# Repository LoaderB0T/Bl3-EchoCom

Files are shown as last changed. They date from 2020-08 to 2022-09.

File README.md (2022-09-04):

# Borderlands 3 - Echo Device

This repo contains all the needed files to create your own 3D printed Echo Com from Borderlands 3.
I put lots of images in the repo so the size got quite big, sorry for that 🤷‍♂️.

If you need additional information or have any questions please just open an issue and I will try to answer them 😀.
And please, if you decide to give it a shot and you use my model, please please send me pictures of the result! :) Just open an issue here to show off your amazing work.

## Printing

- I printed all opaque parts with PLA filament with 0.15mm layer height.
- For the electronics version, the inner projector part was printed with "transparent" PETG filament to let the light of the LEDs pass through.
- I Recommend printing more or less everything with full support to make sure all the complex parts get printed properly.
- Removing the supports is quite easy with this model.

## Components for the electronics version

- [4" TFT Display](https://www.waveshare.com/4inch-tft-touch-shield.htm)
  - I really recommend buying exactly this one as the 3D model is designed for exactly this product.
  - It was the only display I found that had the correct size for the EchoCom.
  - You have to remove the pin headers from the backside for it to fit into the model. The required wires then can be re-soldered with a thinner footprint.
- Custom PCB
  - You can find the KiCad project and a finished plot of the PCB in the `pcb` folder.
  - Use a service like [JLCPCB](jlcpcb.com) to have it manufactured or you can of course do it yourself :)
- Electronic Components:
  - 1x Atmega328P-PU
  - 8x Push Button
  - 2x 22pF ceramic capacitors
  - 1x 16MHz Crystal
  - 3x 100nF foil capacitor
  - 1x 10K Ohm resistor
  - 2x Digital RGB LEDs (eg WS2812B) (one or maybe more than two might also work for you)
  - 2x Screw Terminals (optional, you can also solder the power wires)
  - Pin Header (optional, you can also solder the wires, but I recommend the headers!)
    - 2x 3-pin
    - 2x 5-pin
    - 1x 6-pin
- Some sort of power source (I have not yet figured this out)
- Wires (with correct heads depending on your pin headers)

## Code

The code is very, very unfinished!
I recommend [Visual Studio Code](https://code.visualstudio.com/) to edit the code. The code is a [PlatformIO](https://platformio.org/) project, so I recommend the [PlatformIO extension](https://marketplace.visualstudio.com/items?itemName=platformio.platformio-ide) for VSCode.

## Images

| | | |
| :---: | :---: | :---: |
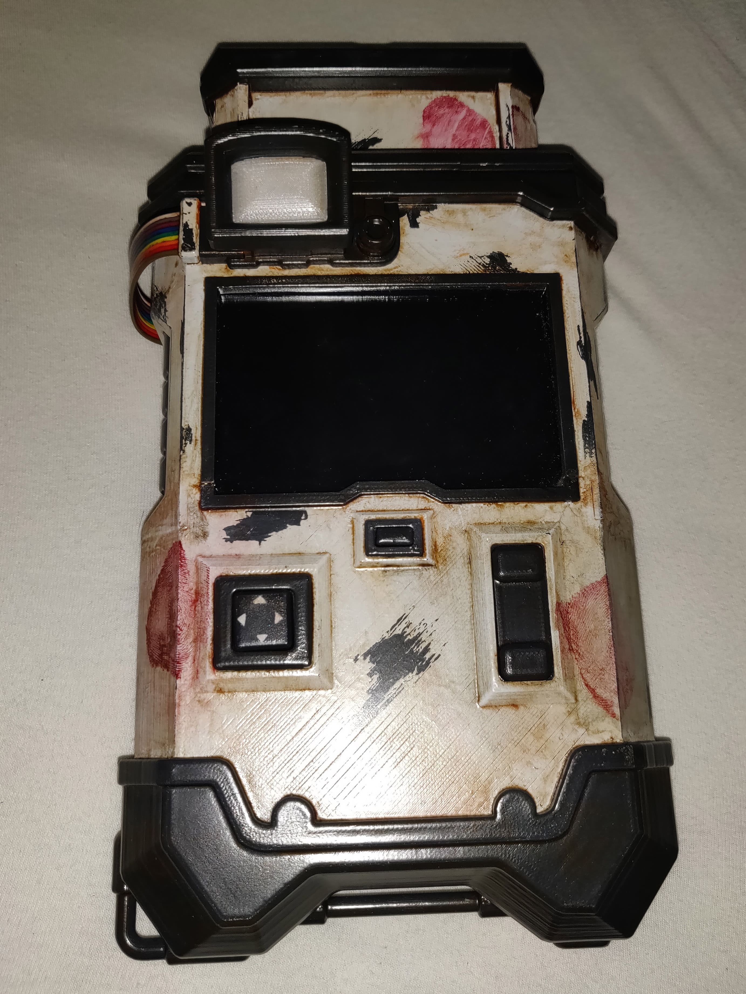
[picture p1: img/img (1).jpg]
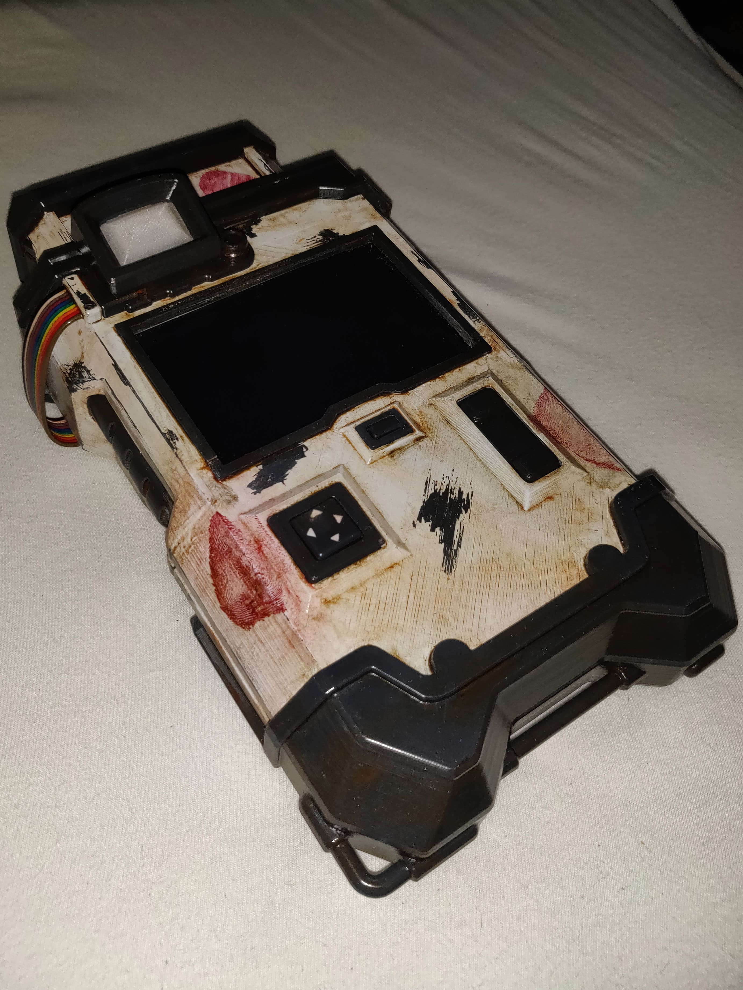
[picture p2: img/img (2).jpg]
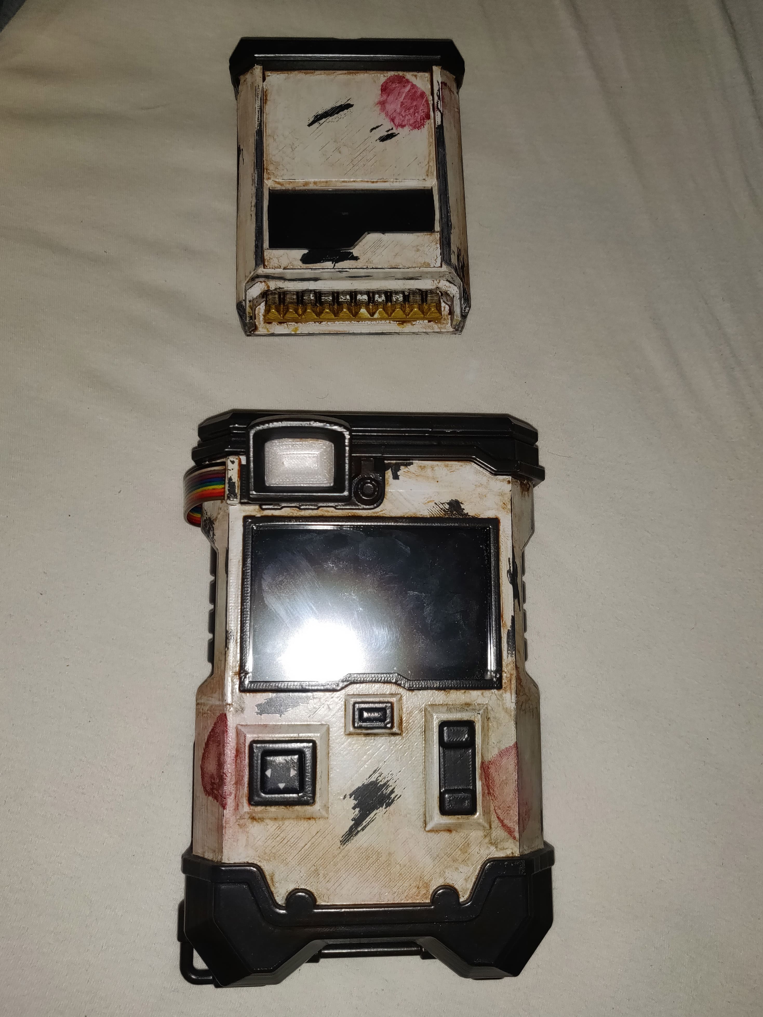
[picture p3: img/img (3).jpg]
|  |   |   |
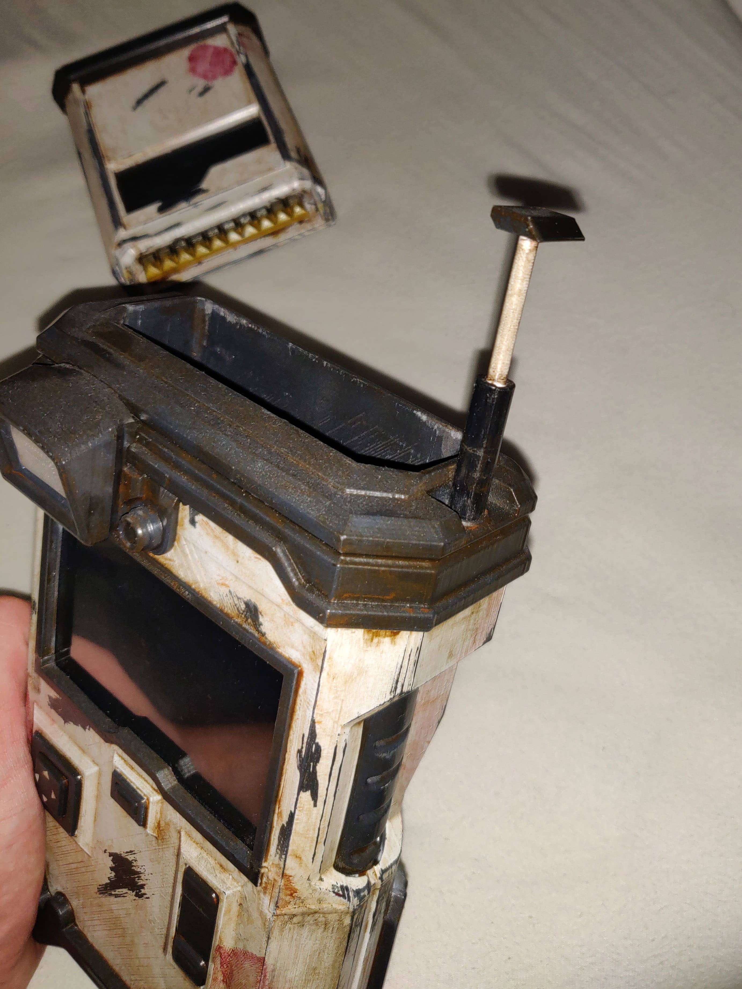
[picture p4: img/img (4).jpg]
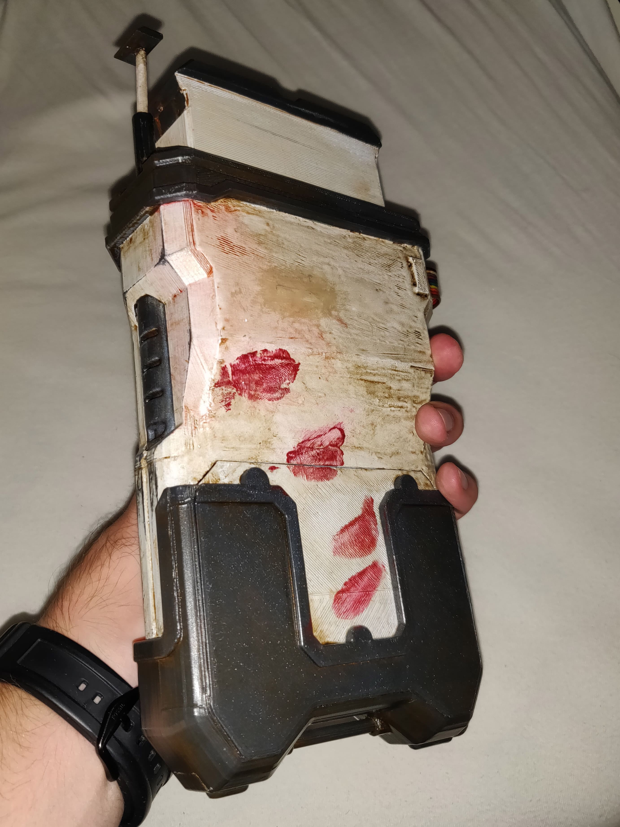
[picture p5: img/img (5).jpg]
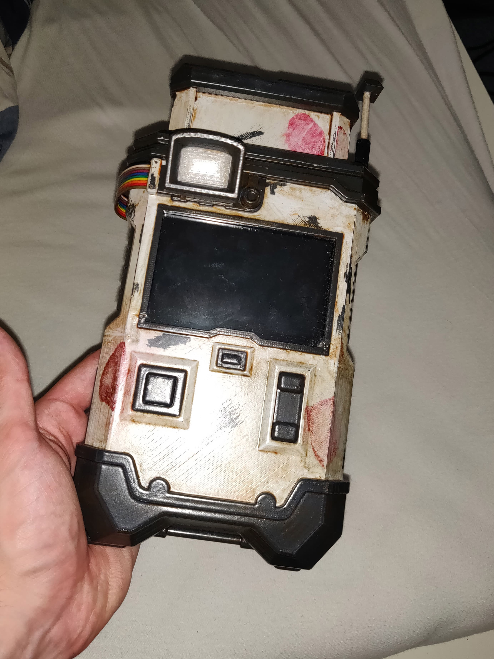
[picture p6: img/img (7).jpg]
|  |   |   |
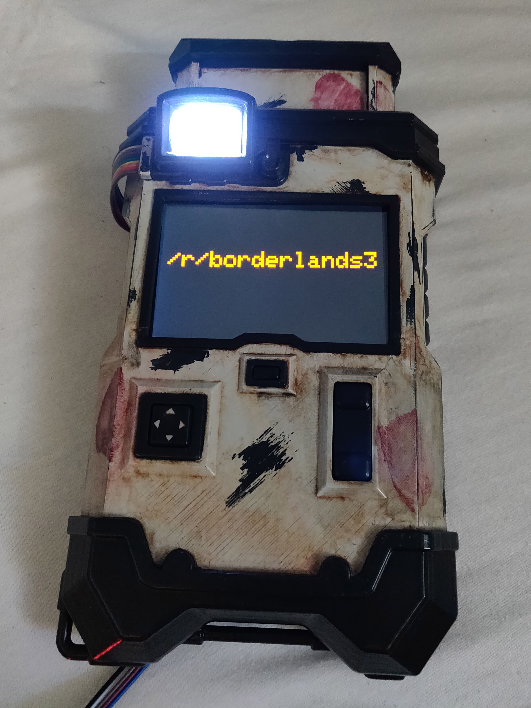
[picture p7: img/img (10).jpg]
|  |  |  |

## Progress images

| | | |
| :---: | :---: | :---: |
|  |  |  |
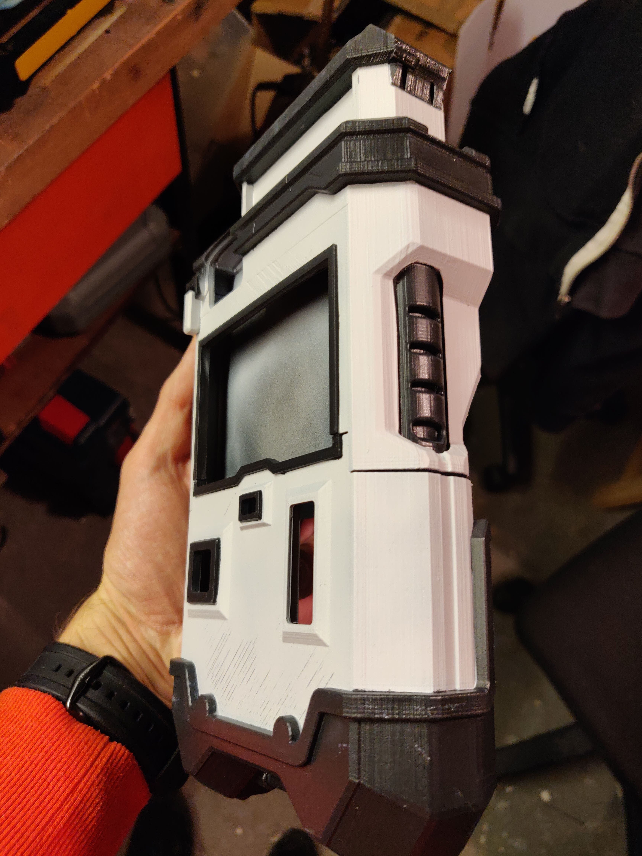
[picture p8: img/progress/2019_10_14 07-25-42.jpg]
|  |  |  |
|  |  |  |
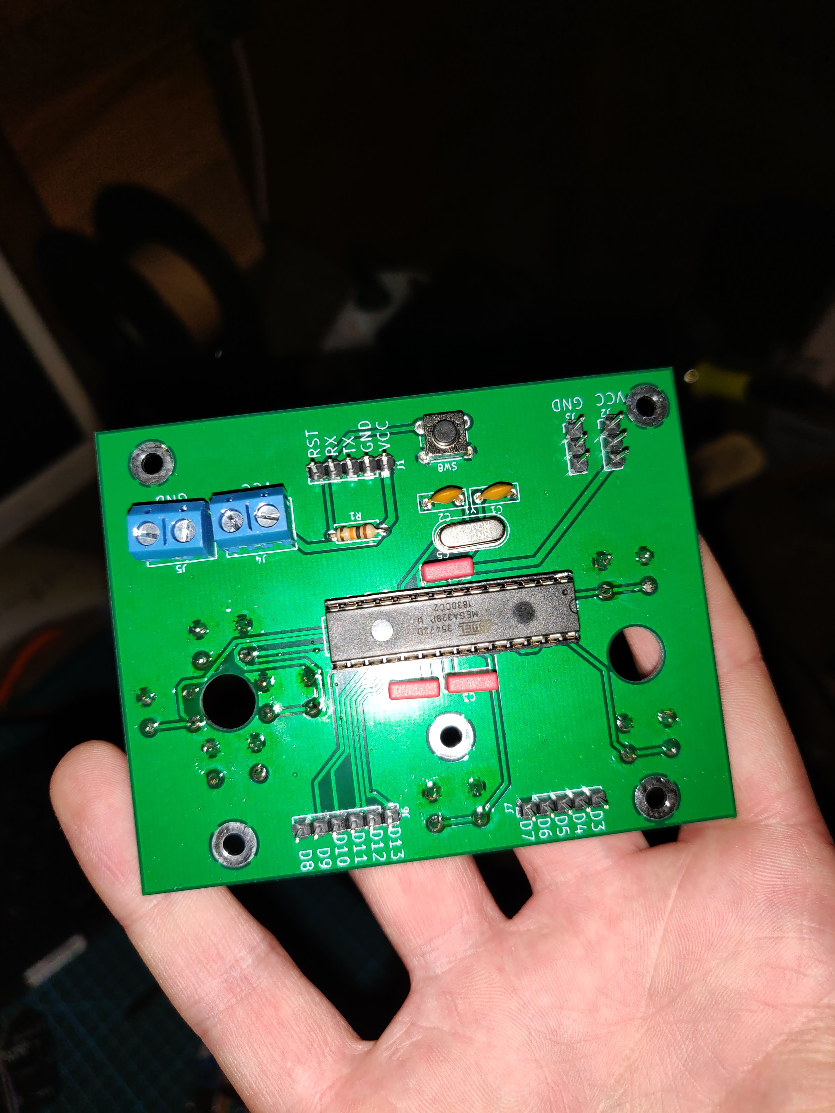
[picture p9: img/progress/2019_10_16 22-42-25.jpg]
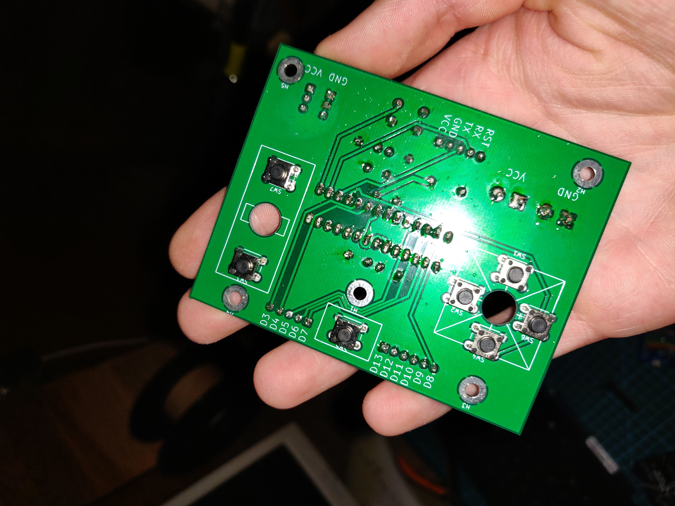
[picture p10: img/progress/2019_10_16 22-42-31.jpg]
|  |  |  |
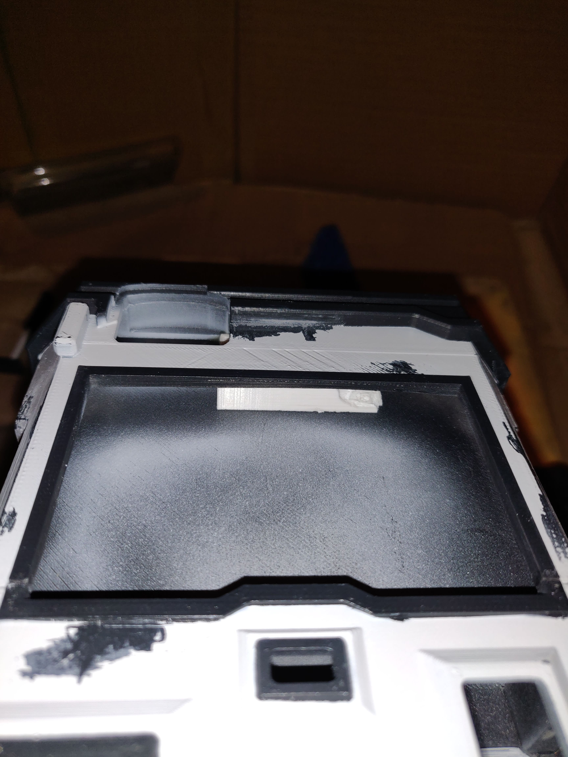
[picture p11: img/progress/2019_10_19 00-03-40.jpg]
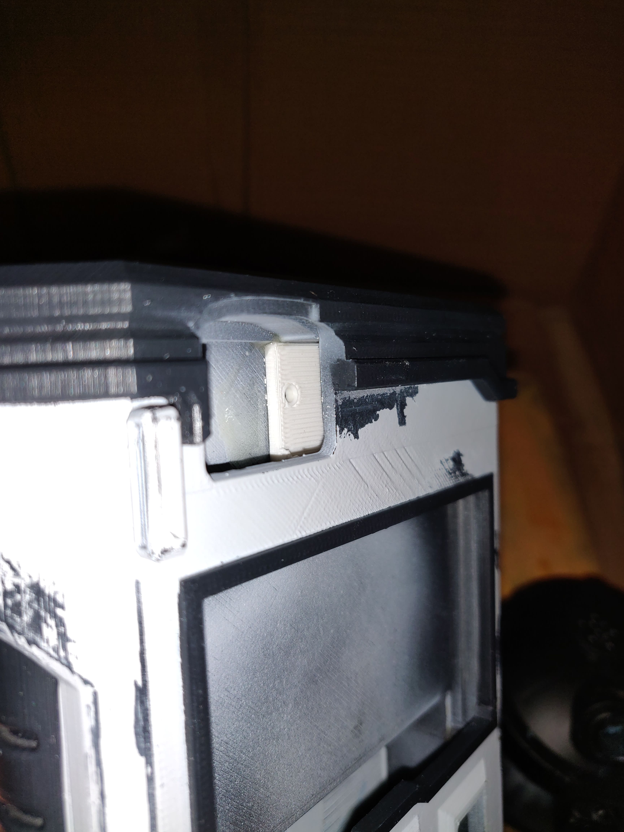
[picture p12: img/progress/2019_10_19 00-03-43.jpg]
|  |  |  |
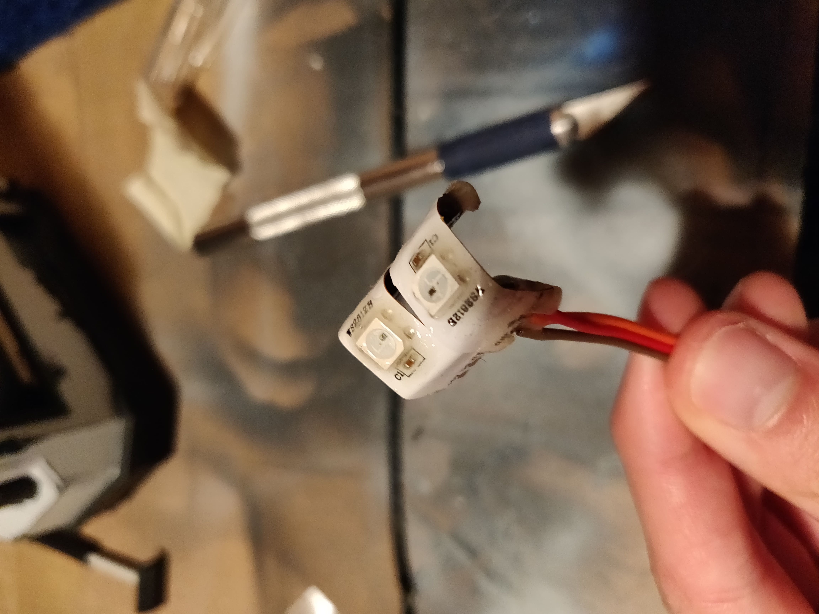
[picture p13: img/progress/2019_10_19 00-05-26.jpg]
|  |  |  |
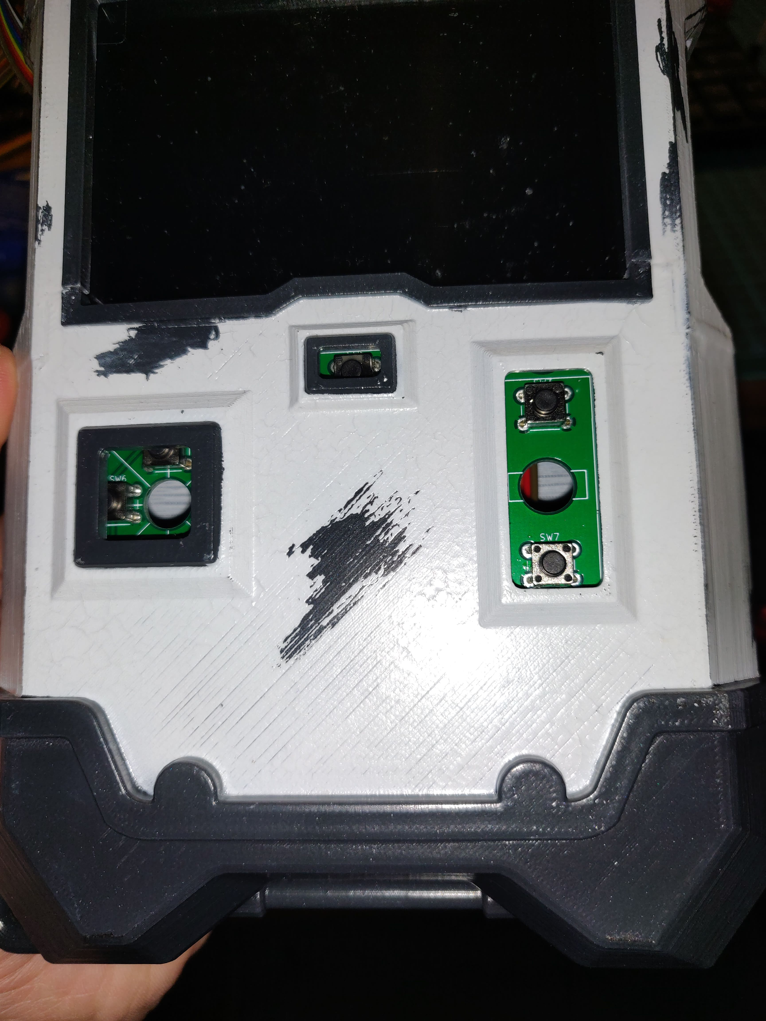
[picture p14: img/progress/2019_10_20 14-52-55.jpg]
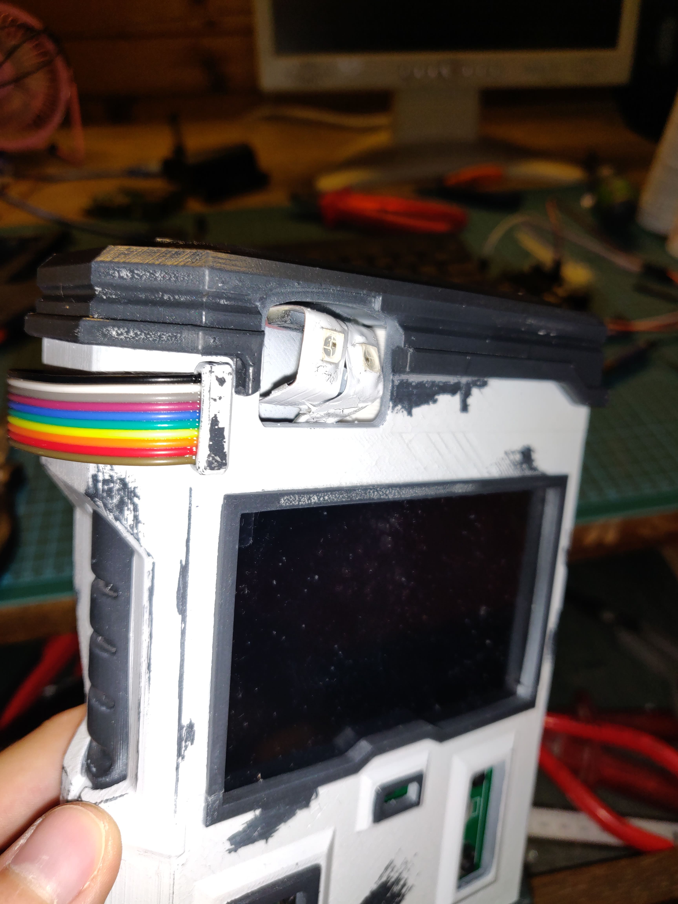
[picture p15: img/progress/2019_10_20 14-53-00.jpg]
|  |  |  |
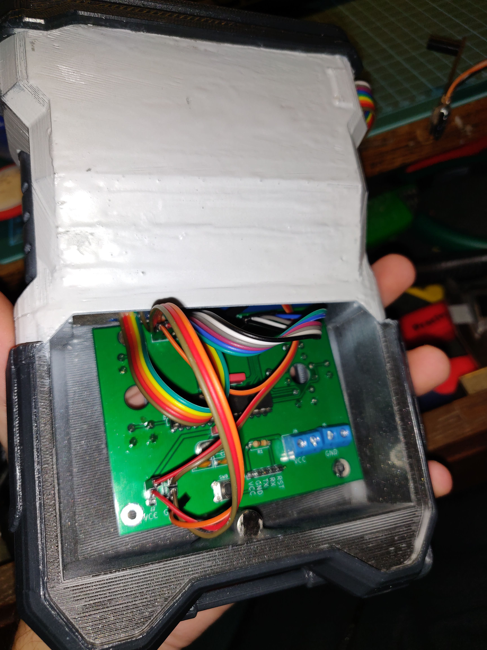
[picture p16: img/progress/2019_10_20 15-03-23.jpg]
|  |  |  |
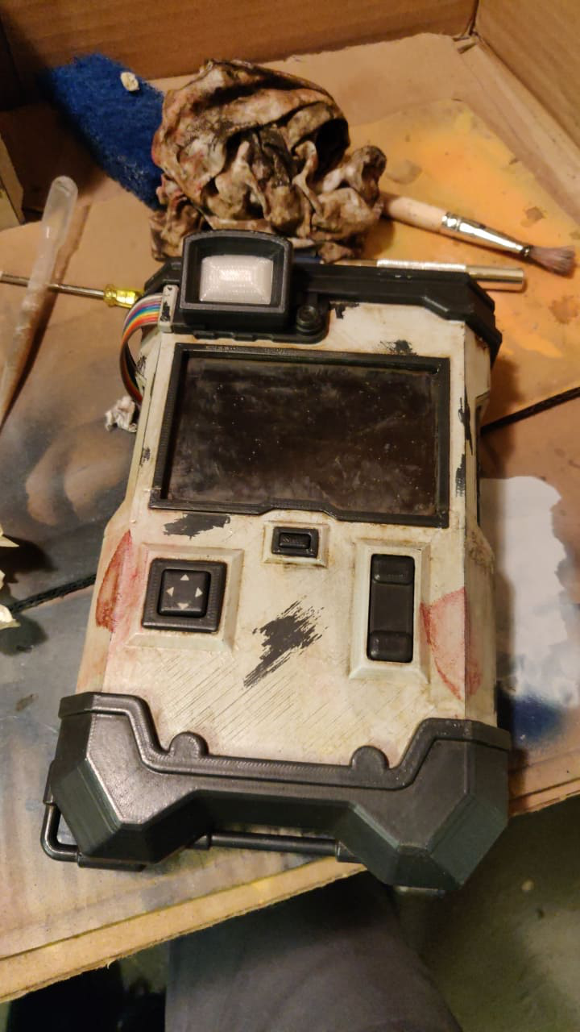
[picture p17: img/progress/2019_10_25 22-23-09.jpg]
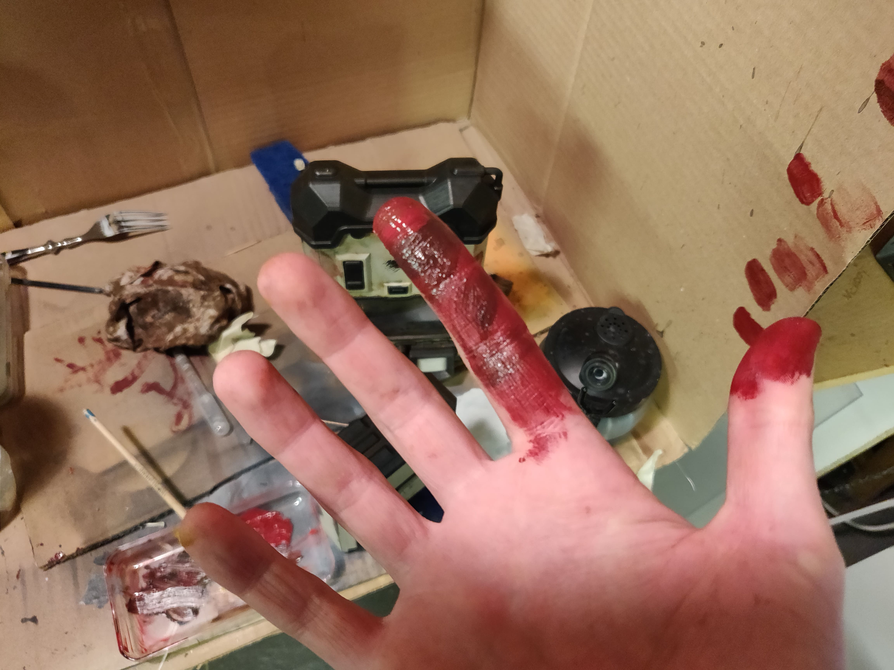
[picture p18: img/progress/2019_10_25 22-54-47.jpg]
|  |  |  |
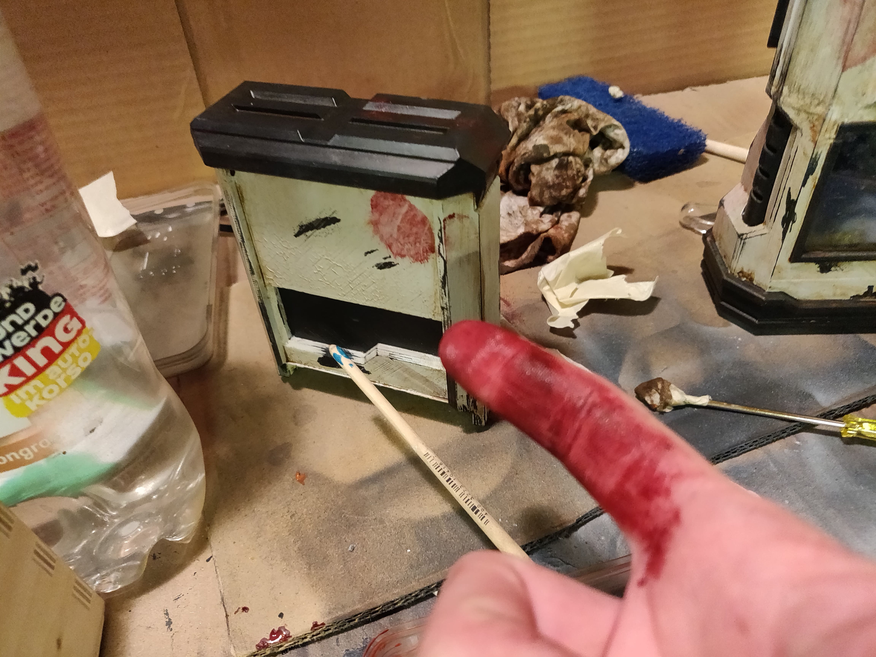
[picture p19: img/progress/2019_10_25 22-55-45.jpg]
|  |  |

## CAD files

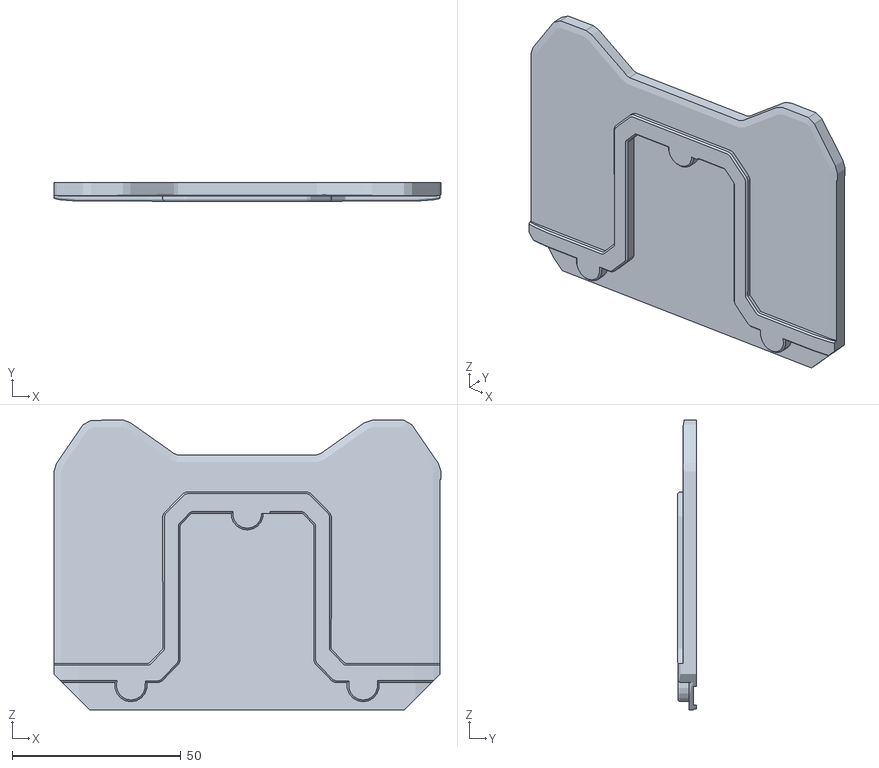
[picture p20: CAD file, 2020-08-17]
stl/electronics version/echoCom BackPlane.stl
114.6 x 5.52 x 85.8

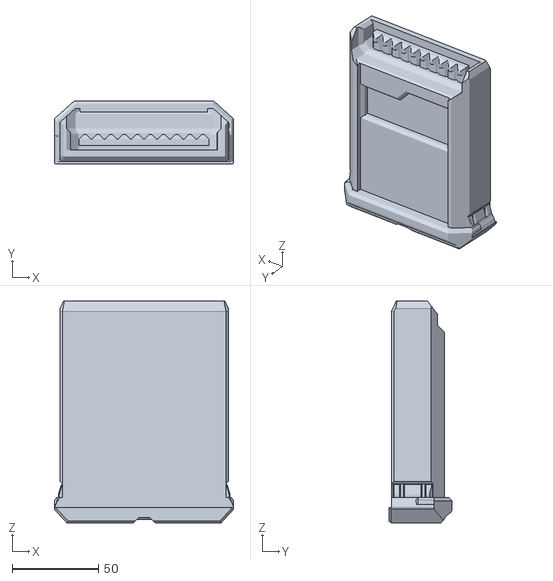
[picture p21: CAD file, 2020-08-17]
stl/solid version/echoCom Solid disk.stl
103.9 x 36.5 x 128.6

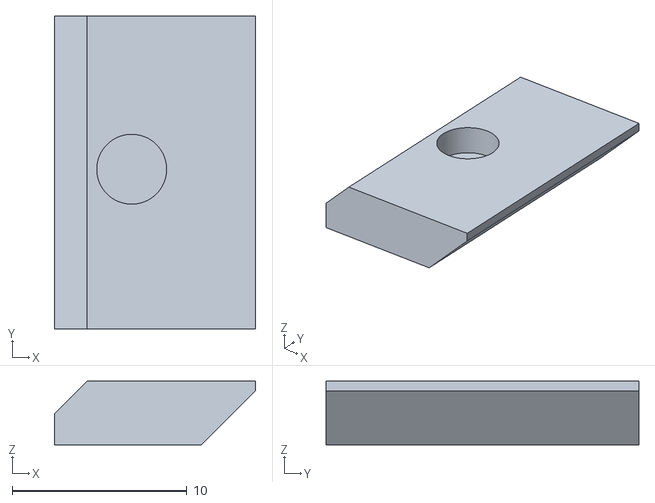
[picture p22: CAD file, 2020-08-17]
stl/electronics version/echoCom AntennaThingy.stl
11.5 x 17.9 x 3.66

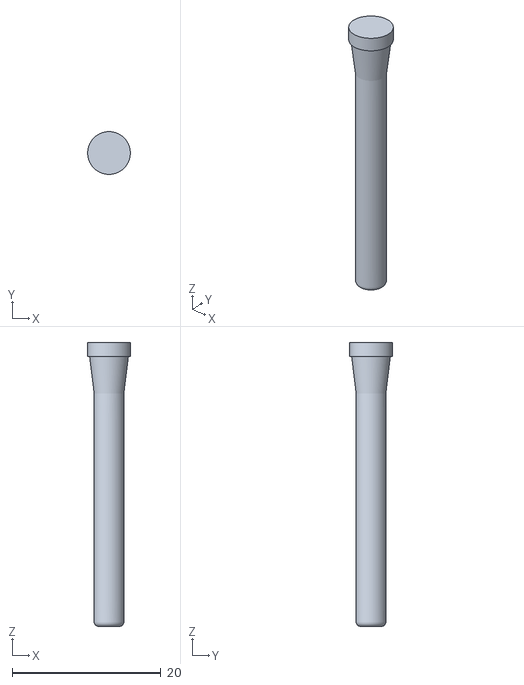
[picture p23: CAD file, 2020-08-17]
stl/solid version/echoCom Solid AntennaUpper.stl
5.74 x 5.74 x 38.1

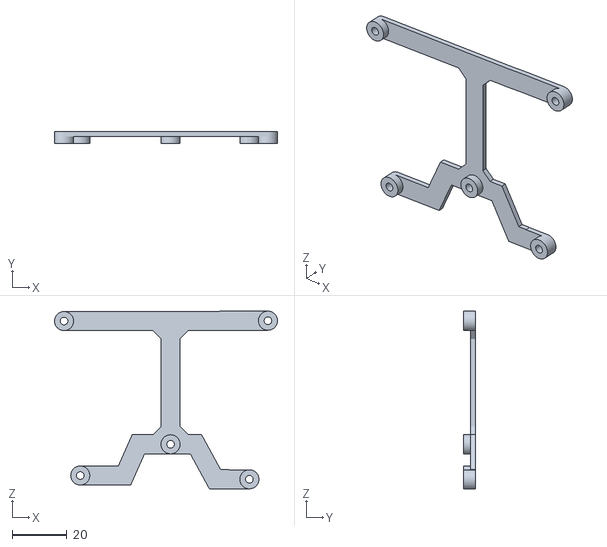
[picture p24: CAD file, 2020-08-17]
stl/electronics version/echoCom PCB Holder.stl
81.7 x 4.50 x 65.1

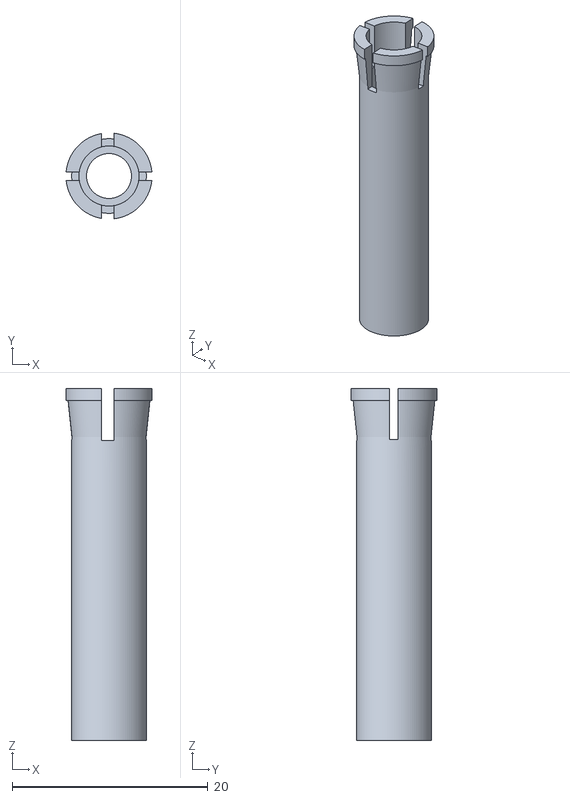
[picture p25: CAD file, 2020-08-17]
stl/solid version/echoCom Solid AntennaLower.stl
8.77 x 8.75 x 36.0

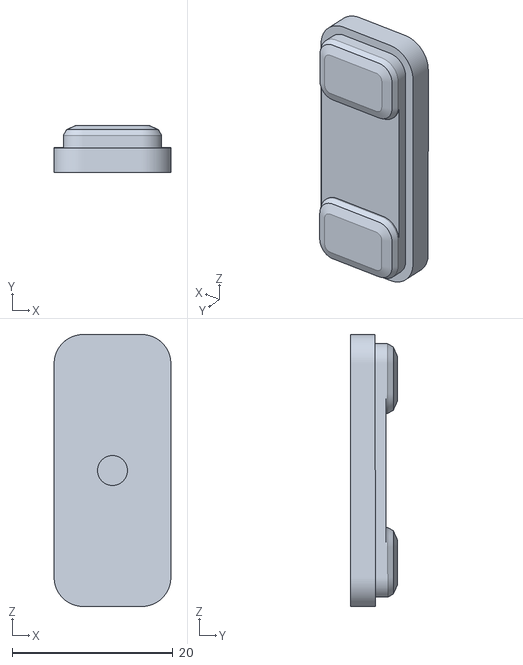
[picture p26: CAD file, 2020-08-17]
stl/electronics version/echoCom ButtonDouble.stl
14.5 x 5.90 x 33.8

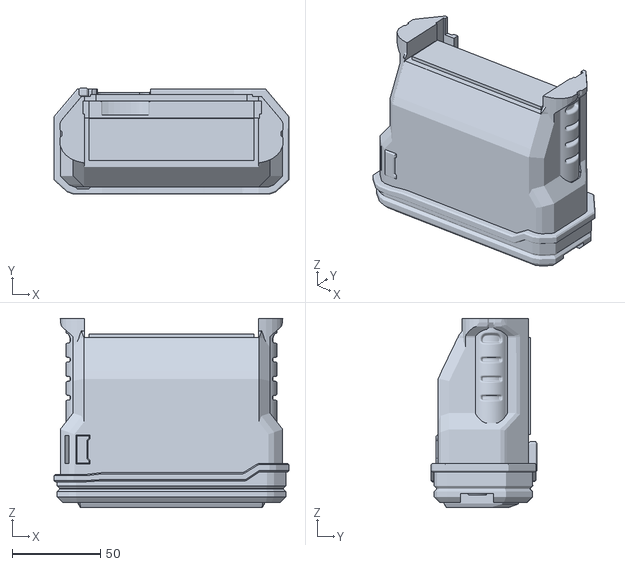
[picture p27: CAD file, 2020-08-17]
stl/electronics version/echoCom Top.stl
133.2 x 60.3 x 107.2

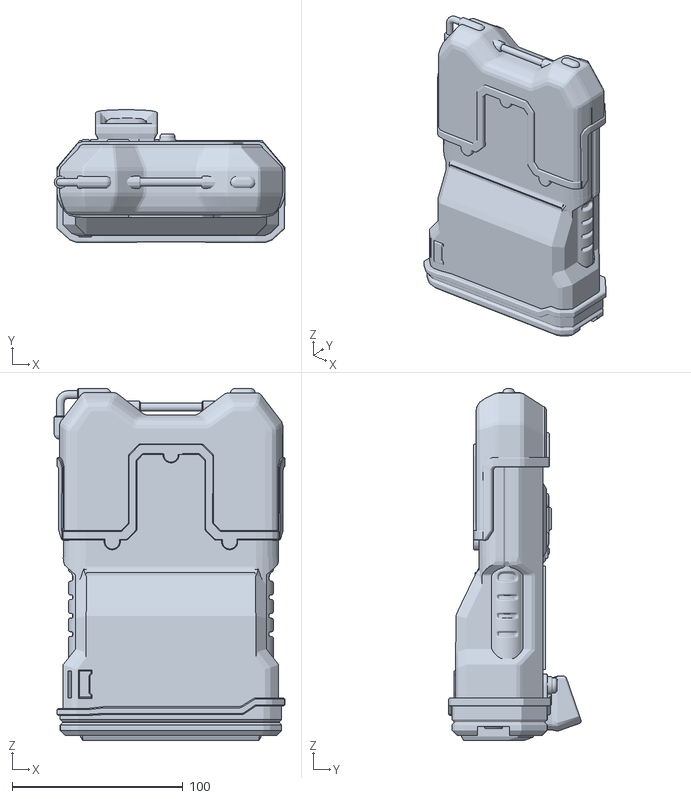
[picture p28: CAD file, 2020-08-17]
stl/solid version/echoCom Solid body.stl
135.0 x 77.6 x 206.0

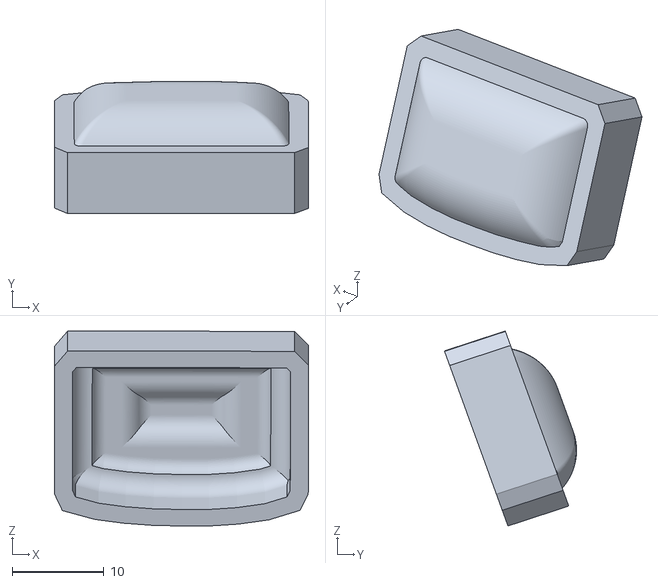
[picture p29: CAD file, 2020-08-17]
stl/electronics version/echoCom ProjectorInner.stl
27.6 x 14.4 x 21.2

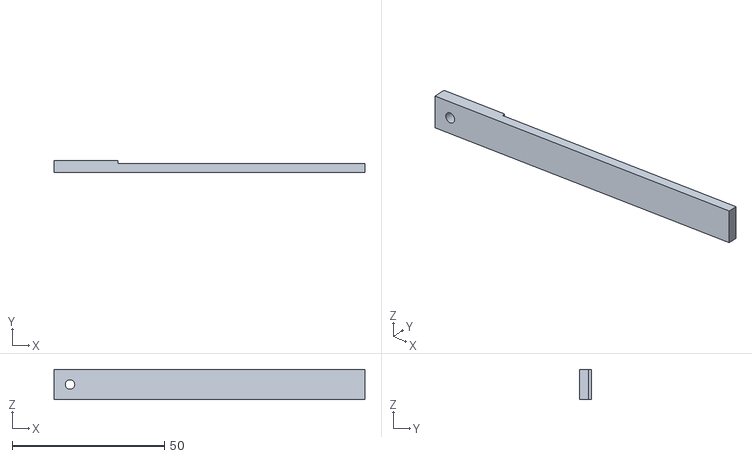
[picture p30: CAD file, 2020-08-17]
stl/electronics version/echoCom pcb holder upperstl.stl
102.0 x 4.00 x 10.0

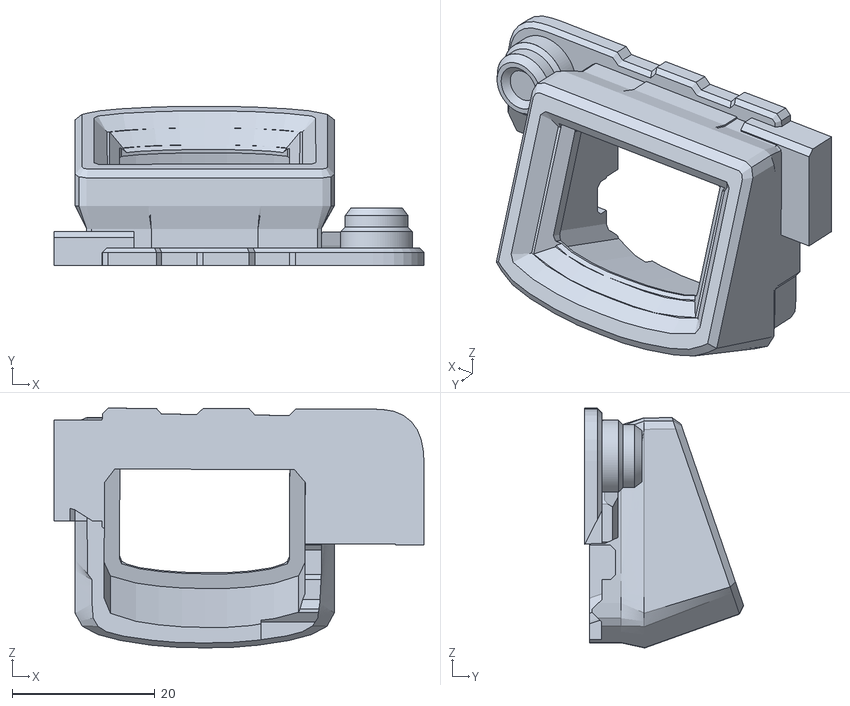
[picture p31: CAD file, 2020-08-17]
stl/electronics version/echoCom Projector.stl
51.9 x 22.3 x 33.6

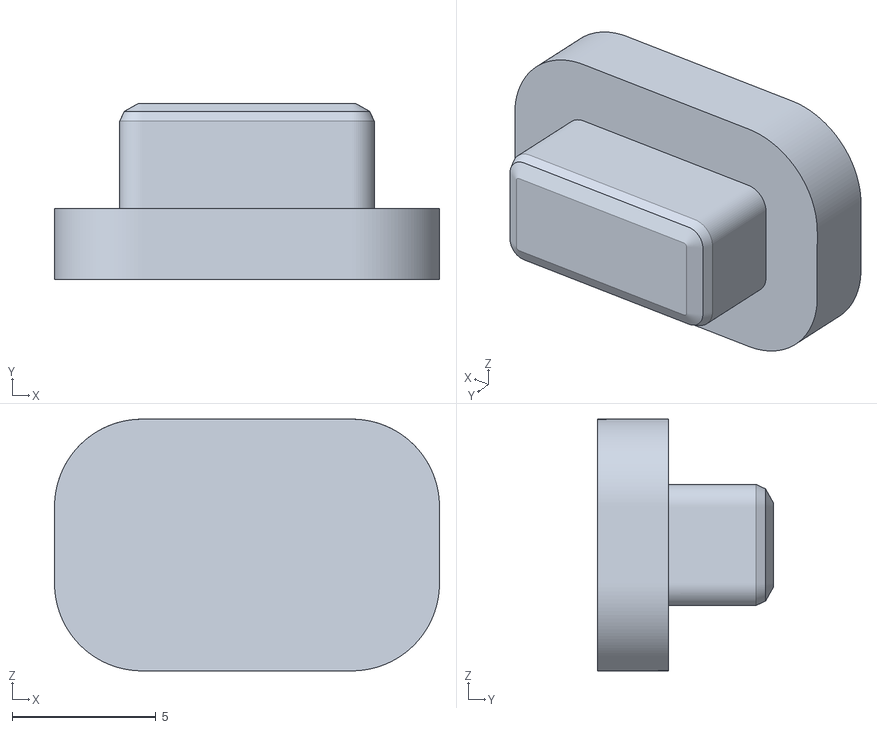
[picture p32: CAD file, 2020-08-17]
stl/electronics version/echoCom ButtonSmall.stl
13.4 x 6.14 x 8.76

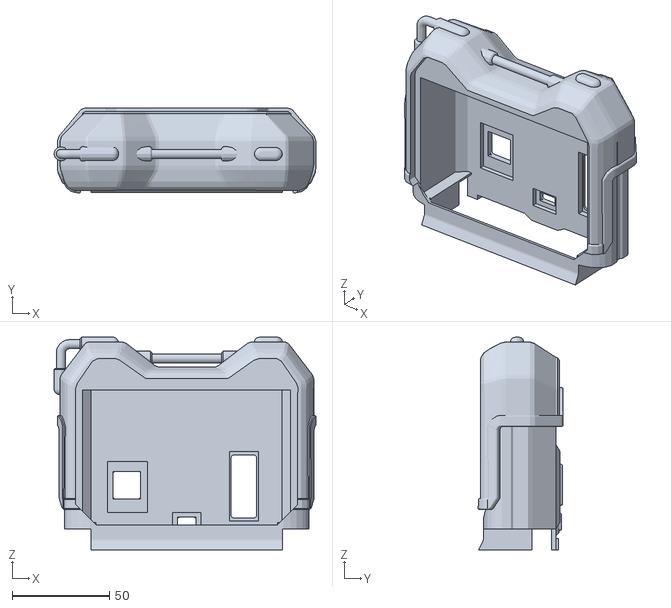
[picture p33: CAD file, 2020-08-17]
stl/electronics version/echoCom Bot.stl
135.0 x 44.0 x 109.6

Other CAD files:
stl/electronics version/echoCom ButtonSquare.stl

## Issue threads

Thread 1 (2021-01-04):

power source suggestion

voxbox31, 2021-01-04:
have you considered using a the echo recording piece (the top removable piece) as a battery bank? maybe a lithium ion circuit or a bank of 18650s?

LoaderB0T, 2021-01-04:
Neat idea, but I think I wouldn't want the echo device to require the 'disk' to work.

Since creating the repo I have not continued working on this project at all (neither software nor hardware)

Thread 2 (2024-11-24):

Could you provide a solid STEP file of the entire device with no internal cutouts please?

tripartist1, 2024-11-24:
Trying to adapt this to a phone case for someone and a step file without the cutaways for electrons would make it much easier. Thanks!

LoaderB0T, 2024-11-24:
Hi there! :)

Did you check the solid version in the STL folder? Sounds like it's exactly what you need :)

Regards,
Janik

tripartist1, 2024-11-26:
Hey, I did check but there doesnt seem to be one single "full model" that isn't already split up unless I missed it. I also use CAD to do my modeling so the STL format makes it somewhat difficult to edit, that's why I requested the step format if possible.

LoaderB0T, 2024-11-28:
I appreciate that the STL might not be as comfortable to work with as a STEP file. Unfortunately, at this moment, I can't provide you with a STEP version.
If you decide to work with the STLs, the solid version has a few STLs, but the main body of the device is [one single solid STL](https://github.com/LoaderB0T/Bl3-EchoCom/blob/master/stl/solid%20version/echoCom%20Solid%20body.stl).

The other STLs in the folder are the disk and three antenna parts. I am sure you can figure out a way to connect the upper part of the antenna, the disk, and the main body into a single object :)

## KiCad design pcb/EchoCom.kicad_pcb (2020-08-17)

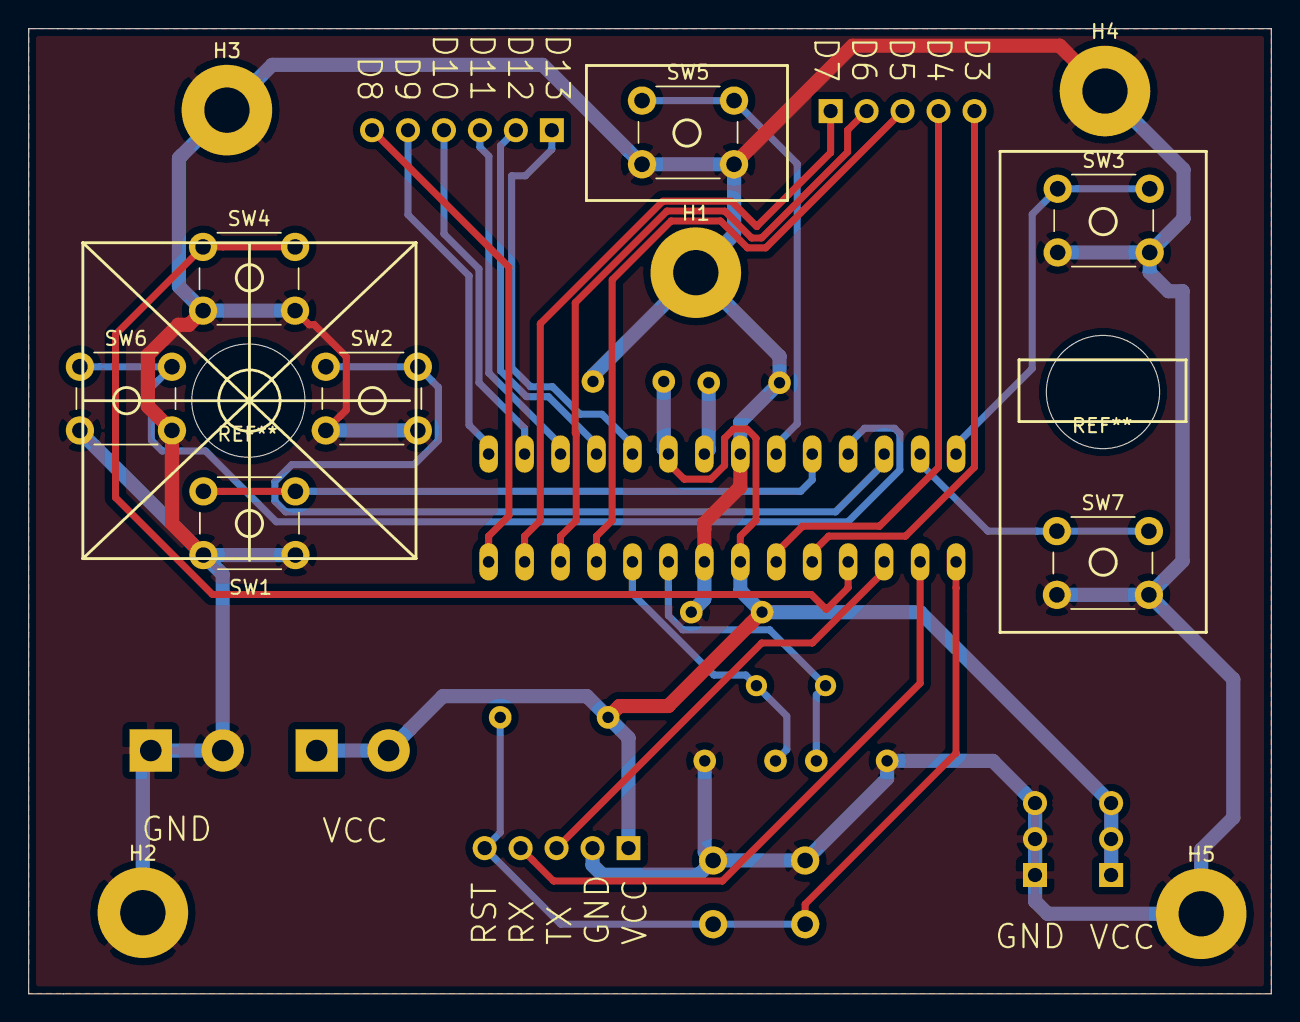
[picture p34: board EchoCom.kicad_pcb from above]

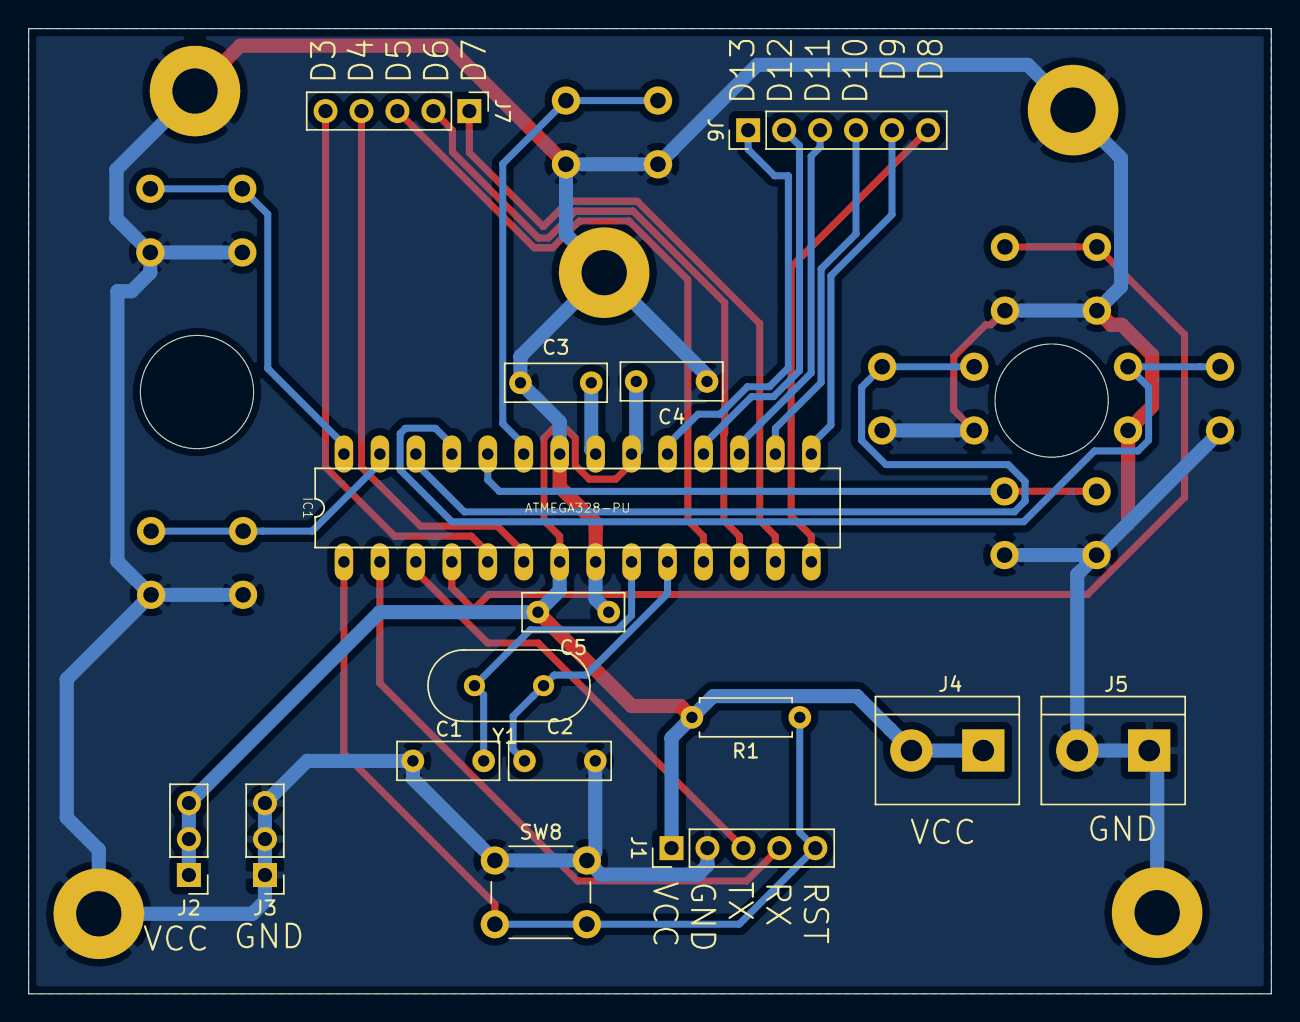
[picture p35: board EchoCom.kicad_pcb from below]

Board: 2 copper layers, 87.8 x 68.2 mm, 28 parts (16 on the bottom side), 26 nets.

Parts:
C1, C2, C3, C4, C5: C; C_Rect_L7.0mm_W2.5mm_P5.00mm
H1, H2, H3, H4, H5: MountingHole_Pad; MountingHole_3.2mm_M3_Pad
IC1: ATMEGA328-PU; DIL28
J1: Conn_Programmer; PinHeader_1x05_P2.54mm_Vertical
J2: Conn_VCC (5v); PinHeader_1x03_P2.54mm_Vertical
J3: Conn_GND; PinHeader_1x03_P2.54mm_Vertical
J4: Screw_Terminal_VCC; TerminalBlock_bornier-2_P5.08mm
J5: Screw_Terminal_GND; TerminalBlock_bornier-2_P5.08mm
J6: Conn_01x06_Male; PinHeader_1x06_P2.54mm_Vertical
J7: Conn_01x05_Male; PinHeader_1x05_P2.54mm_Vertical
R1: R; R_Axial_DIN0207_L6.3mm_D2.5mm_P7.62mm_Horizontal
SW1: SW_Cross_Down; SW_PUSH_6mm_H5mm
SW2: SW_Cross_Right; SW_PUSH_6mm_H5mm
SW3: SW_Dual_Up; SW_PUSH_6mm_H5mm
SW4: SW_Cross_Up; SW_PUSH_6mm_H5mm
SW5: SW_Single; SW_PUSH_6mm_H5mm
SW6: SW_Cross_Left; SW_PUSH_6mm_H5mm
SW7: SW_Dual_Down; SW_PUSH_6mm_H5mm
SW8: SW_Reset; SW_PUSH_6mm_H5mm
Y1: Crystal; Crystal_HC49-4H_Vertical

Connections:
unnamed: C1.1, C2.1, C3.1, C4.1, C5.1, H1.1, H2.1, H3.1, H4.1, H5.1, IC1.8, IC1.22, J1.2, J3.1, J3.2, J3.3, J5.1, J5.2, SW1.2, SW2.2, SW3.2, SW4.2, SW5.2, SW6.2, SW7.2, SW8.1
unnamed: C1.2, IC1.9, Y1.2
unnamed: C2.2, IC1.10, Y1.1
unnamed: C3.2, IC1.21
unnamed: C4.2, C5.2, IC1.7, IC1.20, J1.1, J2.1, J2.2, J2.3, J4.1, J4.2, R1.2
unnamed: IC1.1, J1.5, R1.1, SW8.2
unnamed: IC1.2, J1.4
unnamed: IC1.3, J1.3
unnamed: IC1.4, SW4.1
unnamed: IC1.5, J7.5
unnamed: IC1.6, J7.4
unnamed: IC1.11, J7.3
unnamed: IC1.12, J7.2
unnamed: IC1.13, J7.1
unnamed: IC1.14, J6.6
unnamed: IC1.15, J6.5
unnamed: IC1.16, J6.4
unnamed: IC1.17, J6.3
unnamed: IC1.18, J6.2
unnamed: IC1.19, J6.1
unnamed: IC1.23, SW5.1
unnamed: IC1.24, SW1.1
unnamed: IC1.25, SW6.1
unnamed: IC1.26, SW2.1
unnamed: IC1.27, SW7.1
unnamed: IC1.28, SW3.1

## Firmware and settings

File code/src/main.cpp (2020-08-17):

#include <Arduino.h>
#include <FastLED.h>
#include <SPI.h>
#include "Adafruit_GFX.h"
#include <Waveshare_ILI9486.h>
#include "RgbColorType.h"
#include <Adafruit_ImageReader.h>

#define NUM_LEDS 2
#define DATA_PIN 3
CRGB leds[NUM_LEDS];

Waveshare_ILI9486 tft;

void setup()
{
  // FastLED.addLeds<WS2812, DATA_PIN>(leds, NUM_LEDS).init();

  SPI.begin();
  Serial.begin(9600);
  Serial.println("starting");

  // leds[0].setRGB(0, 0, 255);
  // leds[1].setRGB(0, 0, 255);
  // FastLED.show();

  tft.begin();
  tft.setRotation(1);
  tft.setTextSize(5);
  tft.setCursor(20, 110);
  tft.fillScreen(RgbColorType::rgbToUint(0, 0, 0));
  tft.setTextColor((RgbColorType::rgbToUint(255, 200, 0)));
  tft.print("/r/borderlands3");
}

void loop()
{
  FastLED.addLeds<WS2812, DATA_PIN, EOrder::GRB>(leds, NUM_LEDS);

  auto rndm1 = random(100, 255);
  auto rndm2 = random(100, 255);
  auto rndm3 = random(100, 255);
  auto rndm4 = random(100, 255);
  auto rndm5 = random(30, 255);
  leds[0].setRGB(min(rndm1, rndm2) - 20, rndm1, rndm2);
  leds[1].setRGB(min(rndm3, rndm4) - 20, rndm3, rndm4);
  FastLED.show();

  delay(rndm5);
}
